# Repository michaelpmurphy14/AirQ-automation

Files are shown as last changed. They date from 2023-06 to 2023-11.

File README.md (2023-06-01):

# AirQ automation
 using ESP32C3 chip to collect and analyze air quality data
# Background
Create a sensor platform that can provide air quality data in a self-contained manner while also having the option to interface with an application.
 
A MiCS524 sensor for CO and a BME680 sensor for VOC, eCO2, and Temp/Humidity will connect to a Seeed Studio XIAO nRF52840 board and will be powered by an internal battery. The board will transmit data to an integrated RGB led and audible alert module and will also push data over BLE and WiFi to an application server. The device will be addressable by a single momentary push-button switch for checking battery status, pairing, etc...
 
The device will be able to be charged through the usb-c port on the nRF52840 board, and battery life will be 5-7 days on a single charge under normal load. The device will connect to any MagSafe device and will be able to provide charge-through capabilities when plugged in, as well as the capability to act as a standalone back-up power-bank to the connected device for a limited period
# Hardware Setup
## Bill of Materials
[Seed XIAO ESP32C3](https://www.seeedstudio.com/Seeed-XIAO-ESP32C3-p-5431.html)

[MICS 5524 Sensor](https://wiki.dfrobot.com/Fermion__MEMS_Gas_Sensor___MiCS-5524_SKU_SEN0440)

[BME680 Sensor](https://www.adafruit.com/product/3660)

[Buzzer]

[RGB Led]

[Li-Po Battery]

[QI Wireless Charging Unit]

## Technical Challenges
### Calibration
Each device will have to manually calibrated to provide an accurate range of gas readings from the MIS5524 Sensor. To compare each sensor and chip configuration, we will use onboard tinyML to calibrate to known values and adjust for drift over time

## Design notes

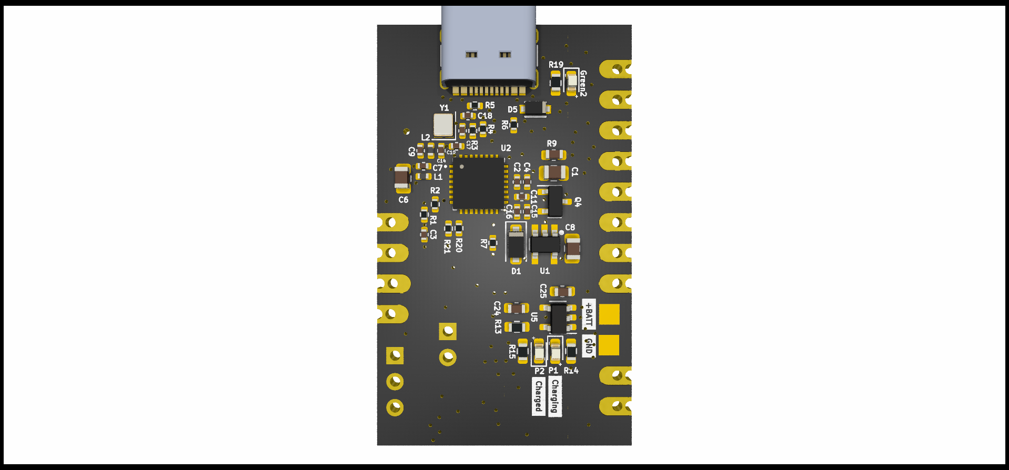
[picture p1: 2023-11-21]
Esp32C3 Project/3D Images/Back 3D.png

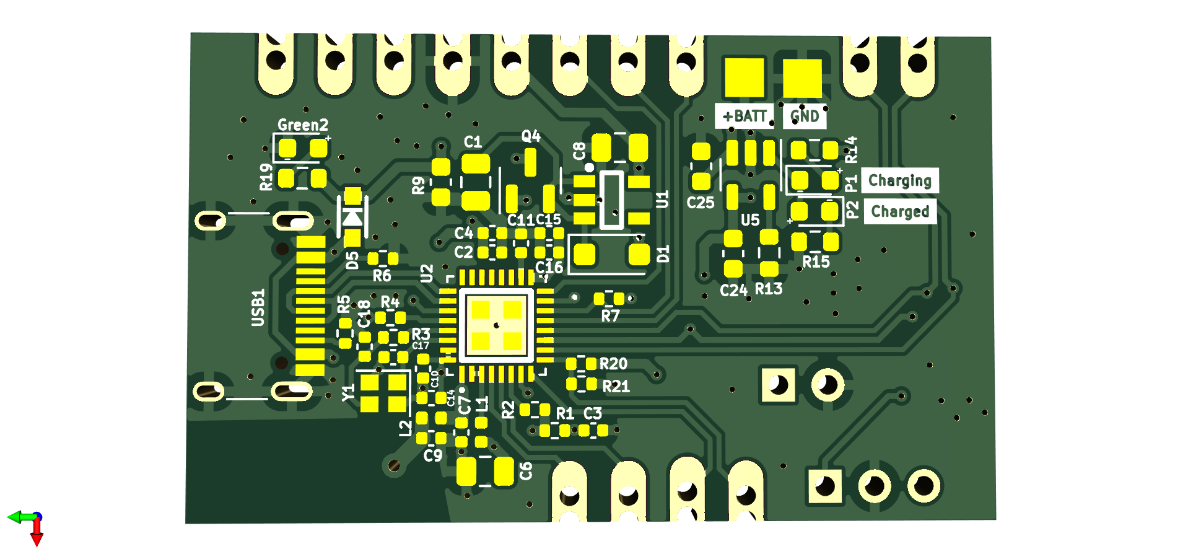
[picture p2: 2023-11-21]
Esp32C3 Project/3D Images/Back 2D.png

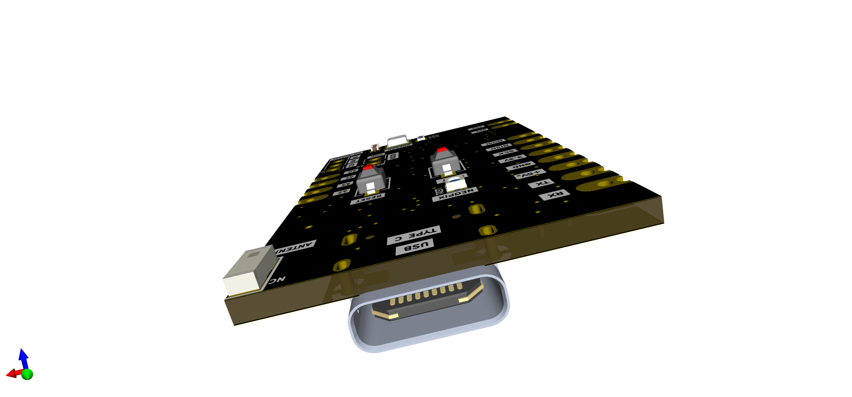
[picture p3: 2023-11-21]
Esp32C3 Project/3D Images/USB.png

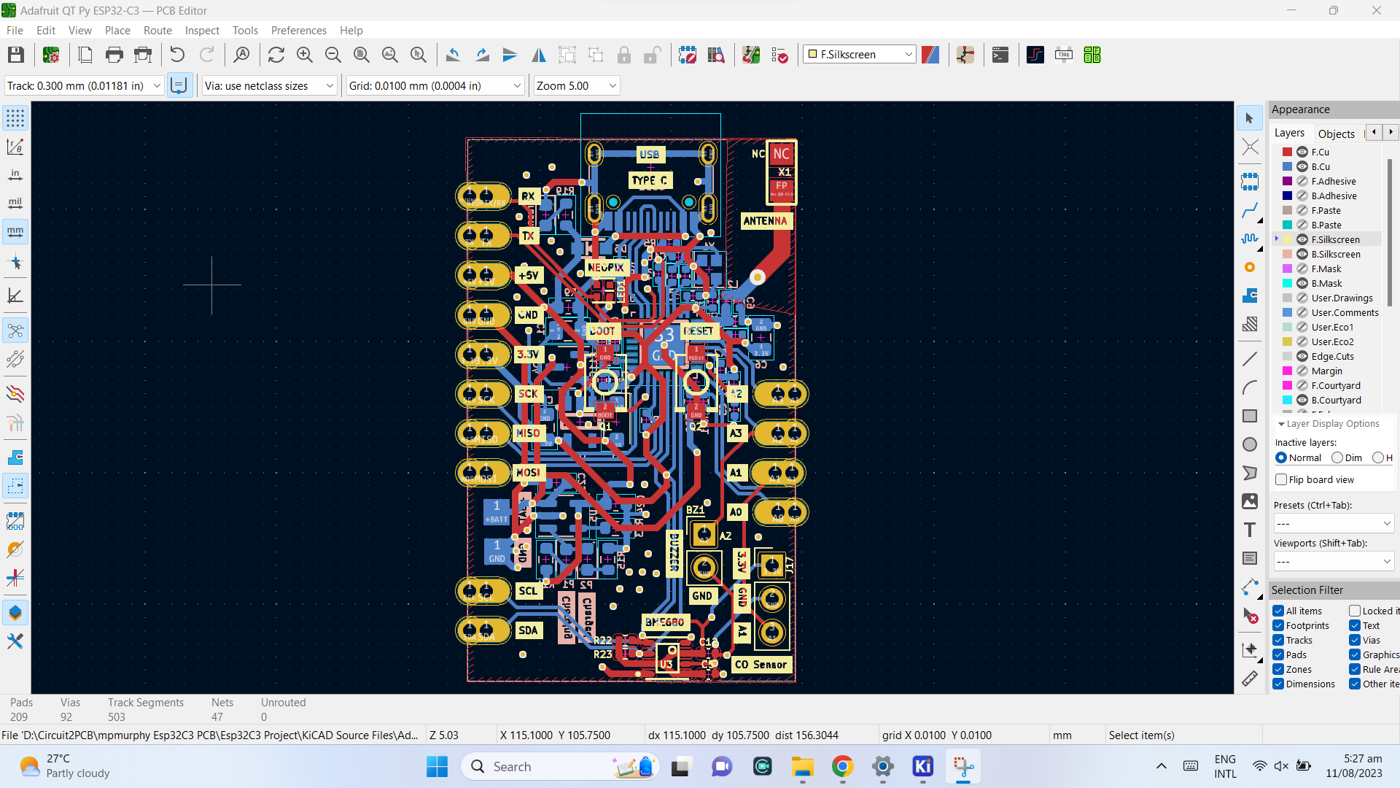
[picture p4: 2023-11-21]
Esp32C3 Project/PCB Layout.png

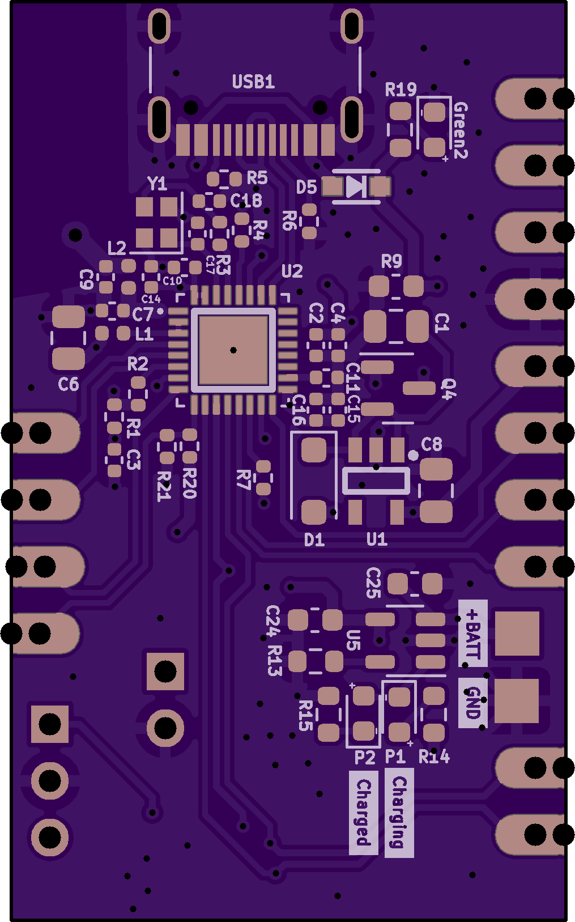
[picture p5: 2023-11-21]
Esp32C3 Project/3D Images/Board Bottom.png

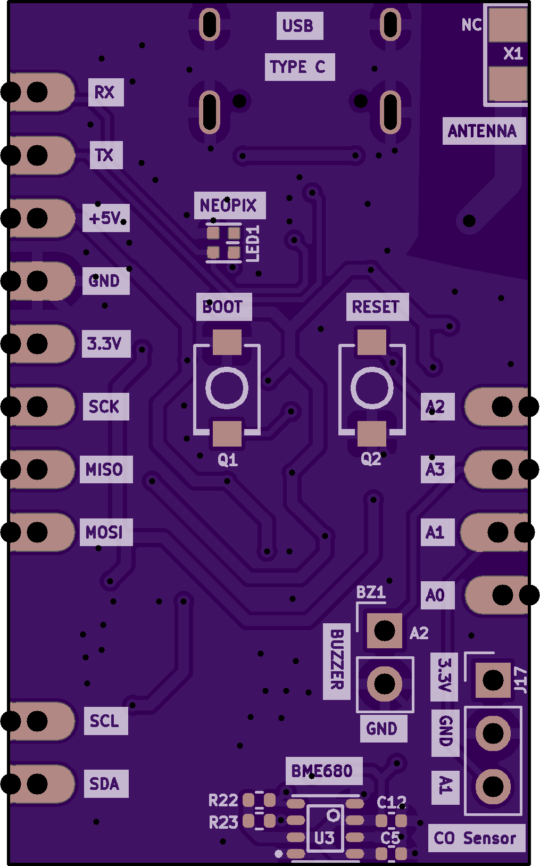
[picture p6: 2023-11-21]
Esp32C3 Project/3D Images/Board Top.png

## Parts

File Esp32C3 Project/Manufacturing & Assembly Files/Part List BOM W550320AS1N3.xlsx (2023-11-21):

Item | Qty | Reference(s) | Value | Footprint | LCSC Part# | Purchase Link
1 | 1 | BZ1 | Buzzer | Connector_PinHeader_2.54mm:PinHeader_1x02_P2.54mm_Vertical | C49661 | https://www.lcsc.com/product-detail/Female-Headers_BOOMELE-Boom-Precision-Elec-C49661_C49661.html
2 | 2 | C1, C8 | 22uF | Ahsan Libs:C_0805_2012Metric | C45783 | https://www.lcsc.com/product-detail/Multilayer-Ceramic-Capacitors-MLCC-SMD-SMT_Samsung-Electro-Mechanics-CL21A226MAQNNNE_C45783.html
3 | 4 | C2, C3, C11, C15 | 1uF | Ahsan Libs:C_0402_1005Metric | C52923 | https://www.lcsc.com/product-detail/Multilayer-Ceramic-Capacitors-MLCC-SMD-SMT_Samsung-Electro-Mechanics-CL05A105KA5NQNC_C52923.html
4 | 5 | C4, C5, C10, C12, C14 | 0.1uF | Ahsan Libs:C_0402_1005Metric | C307331 | https://www.lcsc.com/product-detail/Multilayer-Ceramic-Capacitors-MLCC-SMD-SMT_Samsung-Electro-Mechanics-CL05B104KB54PNC_C307331.html
5 | 1 | C6 | 22uF | Ahsan Libs:C_0805_2012Metric | C45783 | https://www.lcsc.com/product-detail/Multilayer-Ceramic-Capacitors-MLCC-SMD-SMT_Samsung-Electro-Mechanics-CL21A226MAQNNNE_C45783.html
6 | 1 | C7 | 2.7pF | Ahsan Libs:C_0402_1005Metric | C1561 | https://www.lcsc.com/product-detail/Multilayer-Ceramic-Capacitors-MLCC-SMD-SMT_FH-Guangdong-Fenghua-Advanced-Tech-0402CG2R7C500NT_C1561.html
7 | 1 | C9 | 2pF | Ahsan Libs:C_0402_1005Metric | C285089 | https://www.lcsc.com/product-detail/Multilayer-Ceramic-Capacitors-MLCC-SMD-SMT_FH-Guangdong-Fenghua-Advanced-Tech-0402CG2R0B500NT_C285089.html
8 | 1 | C16 | 0.01uF | Ahsan Libs:C_0402_1005Metric | C15195 | https://www.lcsc.com/product-detail/Multilayer-Ceramic-Capacitors-MLCC-SMD-SMT_Samsung-Electro-Mechanics-CL05B103KB5NNNC_C15195.html
9 | 2 | C17, C18 | 16pF | Ahsan Libs:C_0402_1005Metric | C161307 | https://www.lcsc.com/product-detail/Multilayer-Ceramic-Capacitors-MLCC-SMD-SMT_Murata-Electronics-GJM1555C1H160GB01D_C161307.html
10 | 2 | C24, C25 | 10uF | Ahsan Libs:C_0603_1608Metric | C96446 | https://www.lcsc.com/product-detail/Multilayer-Ceramic-Capacitors-MLCC-SMD-SMT_Samsung-Electro-Mechanics-CL10A106MA8NRNC_C96446.html
11 | 1 | D1 | B5817WL | Diode_SMD:D_SOD-123F | C122853 | https://www.lcsc.com/product-detail/Schottky-Barrier-Diodes-SBD_Shikues-B5817WL_C122853.html
12 | 1 | D5 | NSR0320 | Esp32-C3:SOD-323_MINI | C48192 | https://www.lcsc.com/product-detail/Schottky-Barrier-Diodes-SBD_onsemi-NSR0320MW2T1G_C48192.html
13 | 1 | Green2 | Power | Ahsan Libs:LED_0603_1608Metric | C72041 | https://www.lcsc.com/product-detail/Light-Emitting-Diodes-LED_Everlight-Elec-19-217-BHC-ZL1M2RY-3T_C72041.html
14 | 1 | J17 | CO Sensor | Connector_PinHeader_2.54mm:PinHeader_1x03_P2.54mm_Vertical | C541850 | https://www.lcsc.com/product-detail/Female-Headers_XFCN-PM254V-11-03-H85_C541850.html
15 | 1 | L1 | 2nH | Inductor_SMD:L_0402_1005Metric | C98758 | https://www.lcsc.com/product-detail/Inductors-SMD_TDK-MLG1005S2N0CT000_C98758.html
16 | 1 | L2 | 2.2nH | Inductor_SMD:L_0402_1005Metric | C91240 | https://www.lcsc.com/product-detail/Inductors-SMD_Murata-Electronics-LQW15AN2N2C10D_C91240.html
17 | 1 | LED1 | WS2812B_SK6805_1515 | Esp32-C3:SK6805_1515 | C2890035 | https://www.lcsc.com/product-detail/Light-Emitting-Diodes-LED_OPSCO-Optoelectronics-SK6805-EC15_C2890035.html
18 | 1 | P1 | Charging | Ahsan Libs:LED_0603_1608Metric | C125094 | https://www.lcsc.com/product-detail/Light-Emitting-Diodes-LED_Lite-On-LTST-C190KGKT_C125094.html
19 | 1 | P2 | Charged | Ahsan Libs:LED_0603_1608Metric | C125099 | https://www.lcsc.com/product-detail/Light-Emitting-Diodes-LED_Lite-On-LTST-C191KRKT_C125099.html
20 | 1 | Q1 | BOOT | Ahsan Libs:SW-SMD-TS-1088-AR02016 | C720477 | https://www.lcsc.com/product-detail/Tactile-Switches_XUNPU-TS-1088-AR02016_C720477.html
21 | 1 | Q2 | RESET | Ahsan Libs:SW-SMD-TS-1088-AR02016 | C720477 | https://www.lcsc.com/product-detail/Tactile-Switches_XUNPU-TS-1088-AR02016_C720477.html
22 | 1 | Q4 | AO3401A | Package_TO_SOT_SMD:SOT-23 | C15127 | https://www.lcsc.com/product-detail/MOSFETs_Alpha-Omega-Semicon-AO3401A_C15127.html
23 | 2 | R1, R2 | 10K | Ahsan Libs:R_0402_1005Metric | C25744 | https://www.lcsc.com/product-detail/Chip-Resistor-Surface-Mount_UNI-ROYAL-Uniroyal-Elec-0402WGF1002TCE_C25744.html
24 | 1 | R3 | 0 | Ahsan Libs:R_0402_1005Metric | C17168 | https://www.lcsc.com/product-detail/Chip-Resistor-Surface-Mount_UNI-ROYAL-Uniroyal-Elec-0402WGF0000TCE_C17168.html
25 | 1 | R4 | 1k | Ahsan Libs:R_0402_1005Metric | C11702 | https://www.lcsc.com/product-detail/Chip-Resistor-Surface-Mount_UNI-ROYAL-Uniroyal-Elec-0402WGF1001TCE_C11702.html
26 | 2 | R5, R6 | 5.1k | Ahsan Libs:R_0402_1005Metric | C25905 | https://www.lcsc.com/product-detail/Chip-Resistor-Surface-Mount_UNI-ROYAL-Uniroyal-Elec-0402WGF5101TCE_C25905.html
27 | 1 | R7 | 10K | Ahsan Libs:R_0402_1005Metric | C25744 | https://www.lcsc.com/product-detail/Chip-Resistor-Surface-Mount_UNI-ROYAL-Uniroyal-Elec-0402WGF1002TCE_C25744.html
28 | 1 | R9 | 806K | Ahsan Libs:C_0603_1608Metric | C23250 | https://www.lcsc.com/product-detail/Chip-Resistor-Surface-Mount_UNI-ROYAL-Uniroyal-Elec-0603WAF8063T5E_C23250.html
29 | 1 | R13 | 2K | Ahsan Libs:R_0603_1608Metric | C22975 | https://www.lcsc.com/product-detail/Chip-Resistor-Surface-Mount_UNI-ROYAL-Uniroyal-Elec-0603WAF2001T5E_C22975.html
30 | 3 | R14, R15, R19 | 470 | Ahsan Libs:R_0603_1608Metric | C23179 | https://www.lcsc.com/product-detail/Chip-Resistor-Surface-Mount_UNI-ROYAL-Uniroyal-Elec-0603WAF4700T5E_C23179.html
31 | 2 | R20, R21 | 220k | Ahsan Libs:R_0402_1005Metric | C25767 | https://www.lcsc.com/product-detail/Chip-Resistor-Surface-Mount_UNI-ROYAL-Uniroyal-Elec-0402WGF2203TCE_C25767.html
32 | 2 | R22, R23 | 4.7k | Ahsan Libs:R_0402_1005Metric | C25900 | https://www.lcsc.com/product-detail/Chip-Resistor-Surface-Mount_UNI-ROYAL-Uniroyal-Elec-0402WGF4701TCE_C25900.html
33 | 1 | U1 | AP2112K-3.3 | Ahsan Libs:SOT-25-5_L3.0-W1.8-P0.95-LS3.0-BR | C51118 | https://www.lcsc.com/product-detail/Linear-Voltage-Regulators-LDO_Diodes-Incorporated-AP2112K-3-3TRG1_C51118.html
34 | 1 | U2 | ESP32-C3FH4 | Esp32-C3:QFN32_5MM | C2858491 | https://www.lcsc.com/product-detail/Microcontroller-Units-MCUs-MPUs-SOCs_Espressif-Systems-ESP32-C3FH4_C2858491.html
35 | 1 | U3 | BME680 | Ahsan Libs:BME680-LGA-8_L3.0-W3.0-P0.80-TR | C125972 | https://www.lcsc.com/product-detail/Temperature-and-Humidity-Sensor_Bosch-Sensortec-BME680_C125972.html
36 | 1 | U5 | MCP73831-2-OT | Package_TO_SOT_SMD:SOT-23-5 | C424093 | https://www.lcsc.com/product-detail/Battery-Management-ICs_Microchip-Tech-MCP73831T-2ACI-OT_C424093.html
37 | 1 | USB1 | USB_C_Receptacle_USB2.0 | Ahsan Libs:USB_C_Receptacle_HRO_TYPE-C-31-M-12 | C165948 | https://www.lcsc.com/product-detail/USB-Connectors_Korean-Hroparts-Elec-TYPE-C-31-M-12_C165948.html
38 | 1 | X1 | 2.4GHz | Esp32-C3:ANT_2450AT18B100 | C89334 | https://www.lcsc.com/product-detail/Antennas_Johanson-Dielectrics-2450AT18A100E_C89334.html
39 | 1 | Y1 | 40MHz | Crystal:Crystal_SMD_2016-4Pin_2.0x1.6mm | C501798 | https://www.lcsc.com/product-detail/Crystals_TST-TZ1269D_C501798.html

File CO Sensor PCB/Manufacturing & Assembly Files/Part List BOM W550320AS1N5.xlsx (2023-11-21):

Item | Qty | Reference(s) | Value | Footprint | LCSC Part# | Purchase Link
1 | 1 | J17 | CO Sensor Conn | Connector_PinHeader_2.54mm:PinHeader_1x03_P2.54mm_Vertical | C2937625 | https://www.lcsc.com/product-detail/Pin-Headers_XFCN-PZ254V-11-03P_C2937625.html
2 | 2 | R1, R2 | 10K | Ahsan Libs:R_0805_2012Metric | C17414 | https://www.lcsc.com/product-detail/Chip-Resistor-Surface-Mount_UNI-ROYAL-Uniroyal-Elec-0805W8F1002T5E_C17414.html
3 | 1 | R3 | 100K | Ahsan Libs:R_0805_2012Metric | C149504 | https://www.lcsc.com/product-detail/Chip-Resistor-Surface-Mount_UNI-ROYAL-Uniroyal-Elec-0805W8F1003T5E_C149504.html
4 | 1 | U4 | 110-102 | Ahsan Libs:CO Sensor | Carbon Monoxide (CO) Sensor Current | https://www.digikey.com/en/products/detail/spec-sensors-llc/110-102/6136363

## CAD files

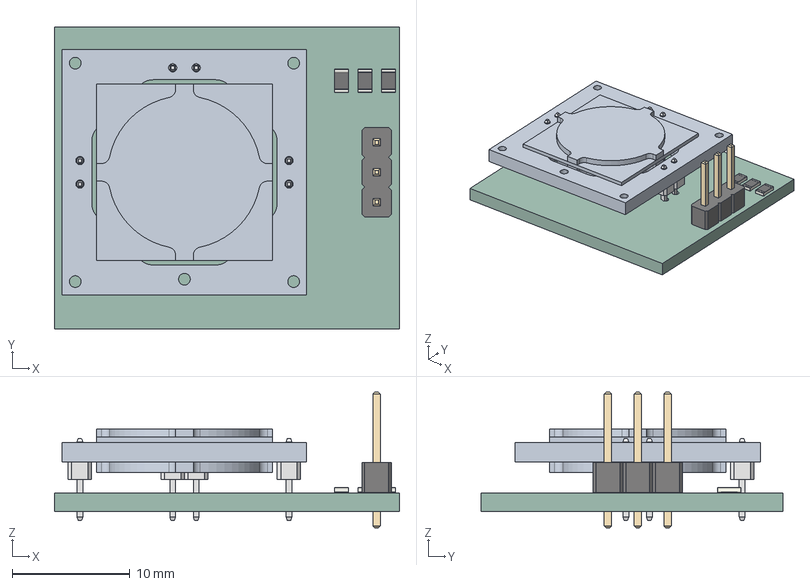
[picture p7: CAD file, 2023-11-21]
CO Sensor PCB/3D Step File/PCB CO Sesnor 3D.step
29.3 x 25.7 x 11.5 mm
_autosave-CO Sesnor Breakout PCB

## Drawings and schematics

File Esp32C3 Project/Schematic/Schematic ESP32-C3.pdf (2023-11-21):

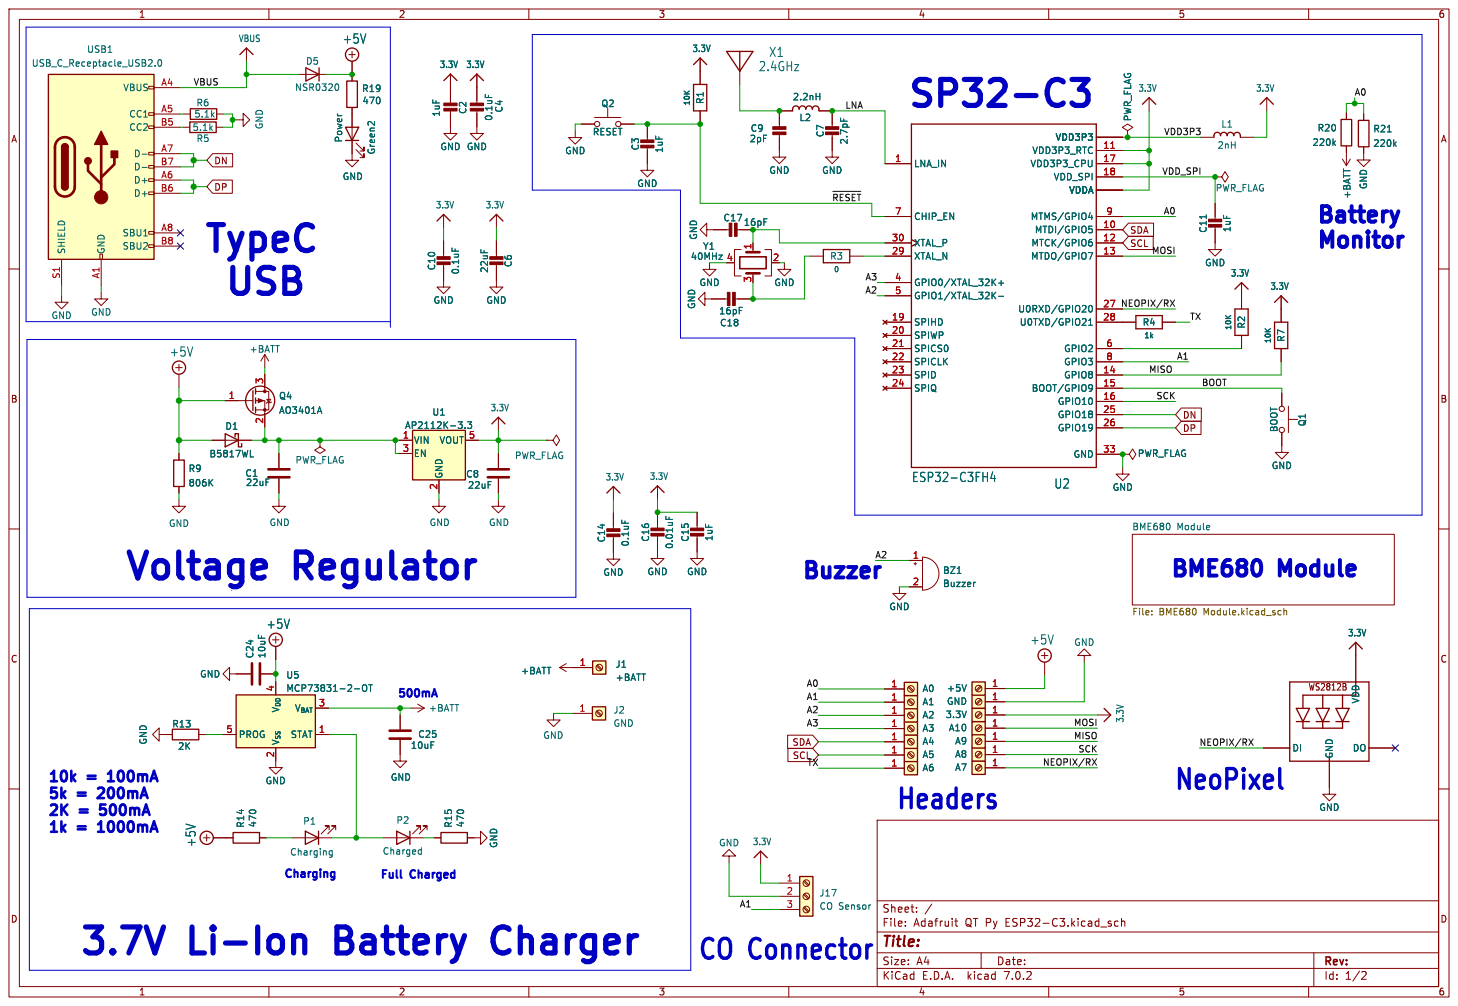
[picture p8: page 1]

2 EN 3 VOUT 5 U1 AP2112K-3.3 GND GND GND GND Q2 RESET X1

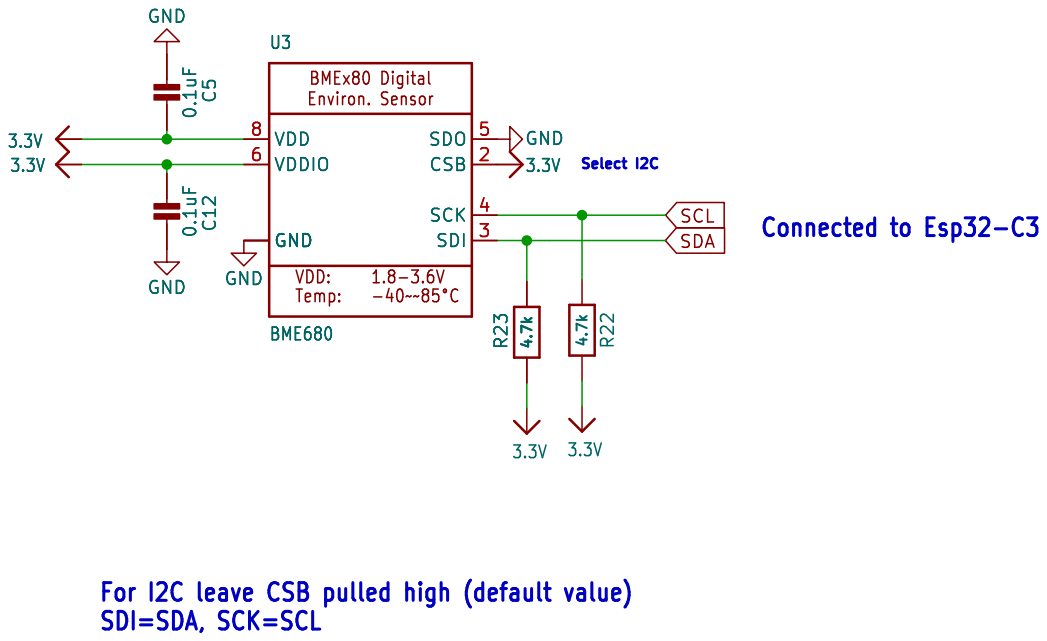
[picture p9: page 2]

SDI=SDA, SCK=SCL

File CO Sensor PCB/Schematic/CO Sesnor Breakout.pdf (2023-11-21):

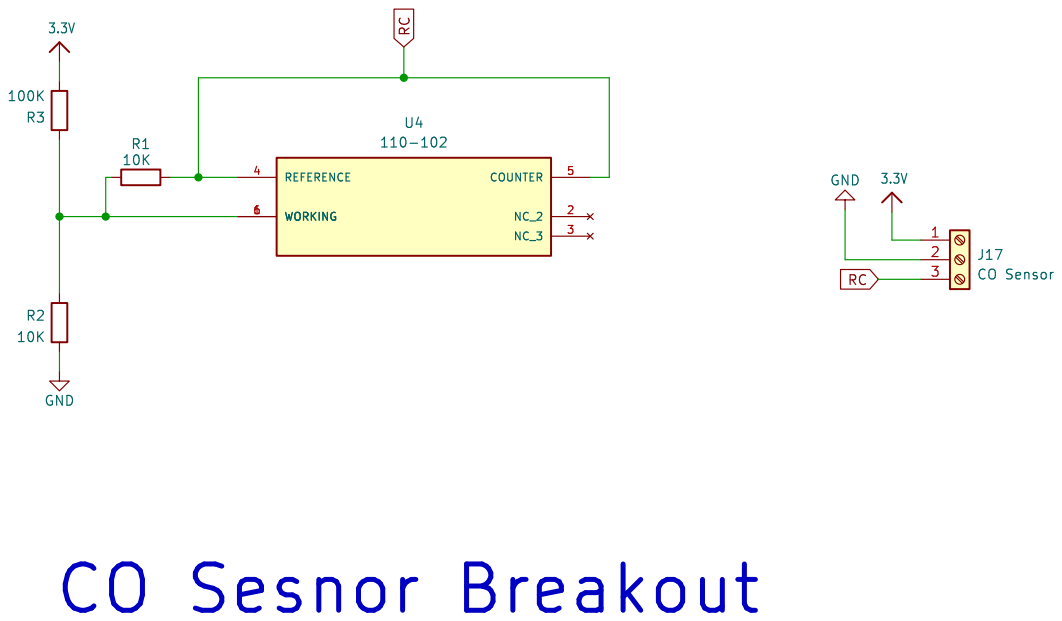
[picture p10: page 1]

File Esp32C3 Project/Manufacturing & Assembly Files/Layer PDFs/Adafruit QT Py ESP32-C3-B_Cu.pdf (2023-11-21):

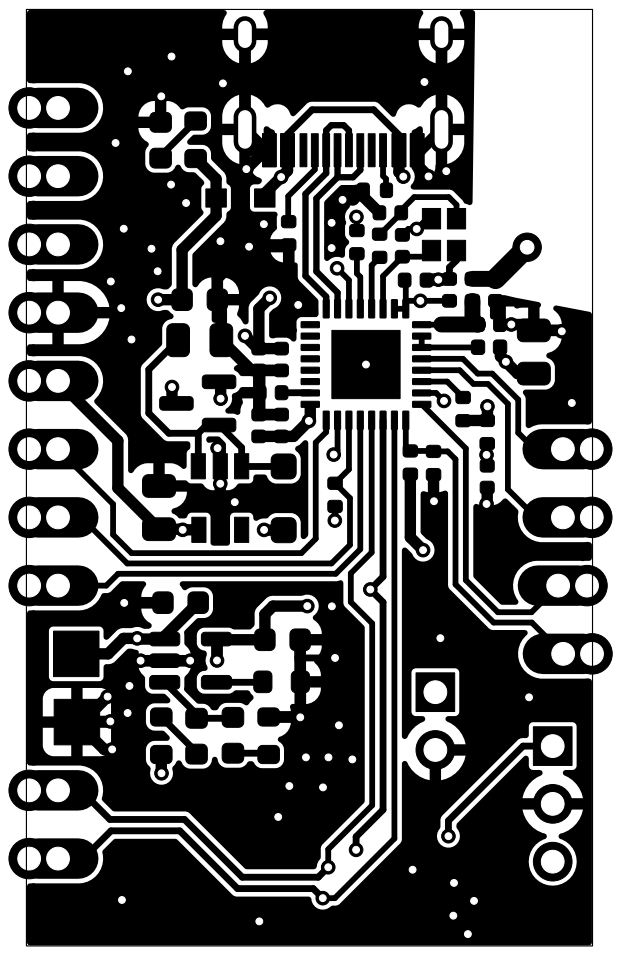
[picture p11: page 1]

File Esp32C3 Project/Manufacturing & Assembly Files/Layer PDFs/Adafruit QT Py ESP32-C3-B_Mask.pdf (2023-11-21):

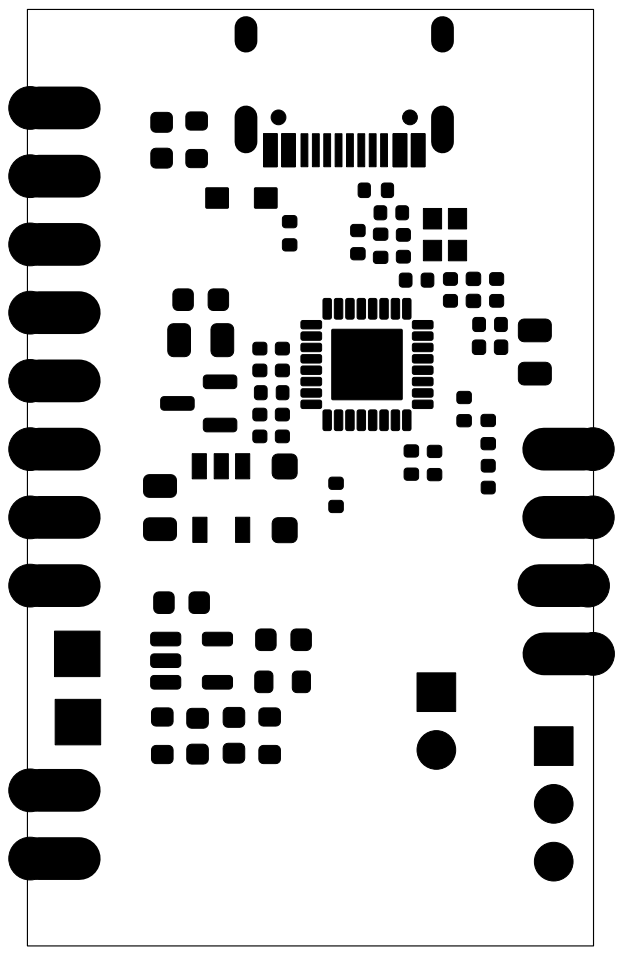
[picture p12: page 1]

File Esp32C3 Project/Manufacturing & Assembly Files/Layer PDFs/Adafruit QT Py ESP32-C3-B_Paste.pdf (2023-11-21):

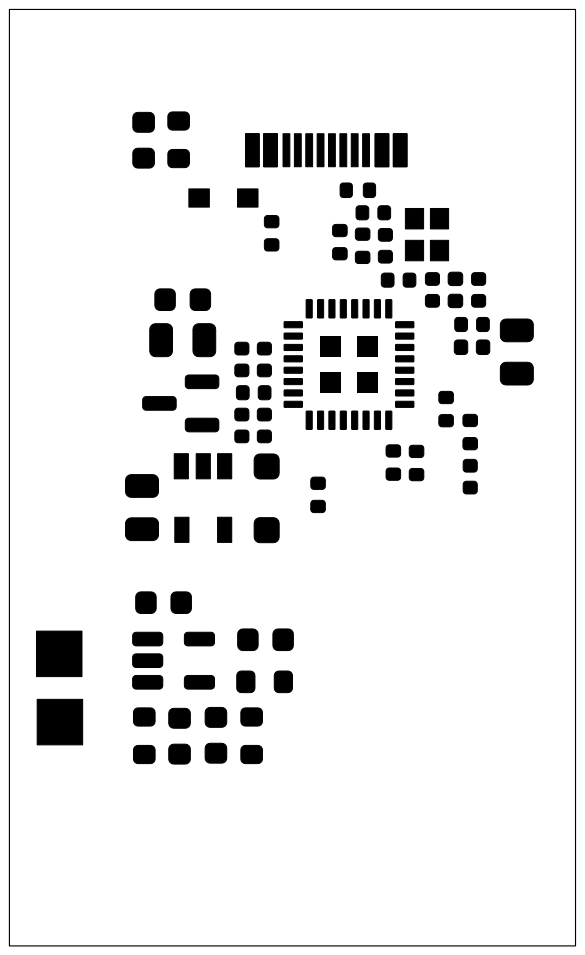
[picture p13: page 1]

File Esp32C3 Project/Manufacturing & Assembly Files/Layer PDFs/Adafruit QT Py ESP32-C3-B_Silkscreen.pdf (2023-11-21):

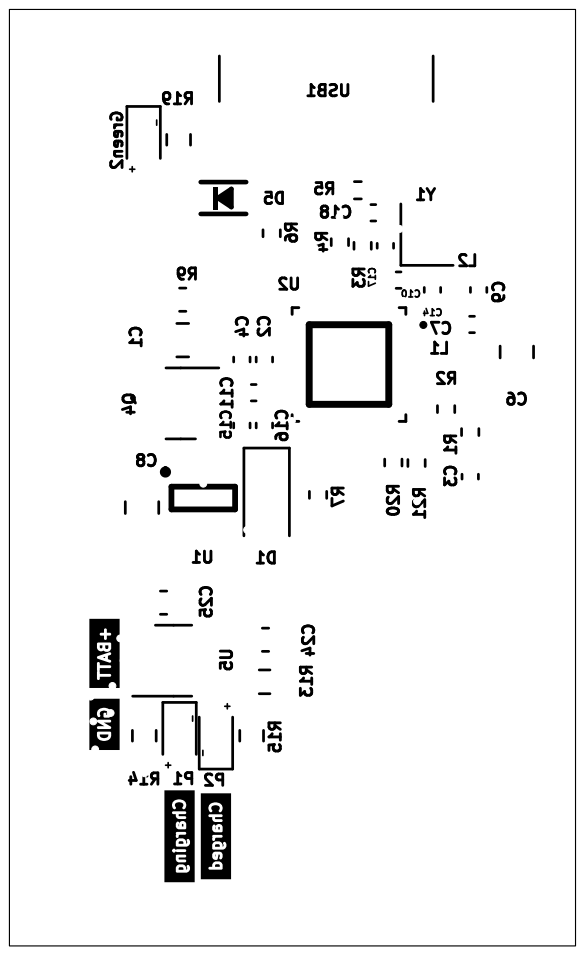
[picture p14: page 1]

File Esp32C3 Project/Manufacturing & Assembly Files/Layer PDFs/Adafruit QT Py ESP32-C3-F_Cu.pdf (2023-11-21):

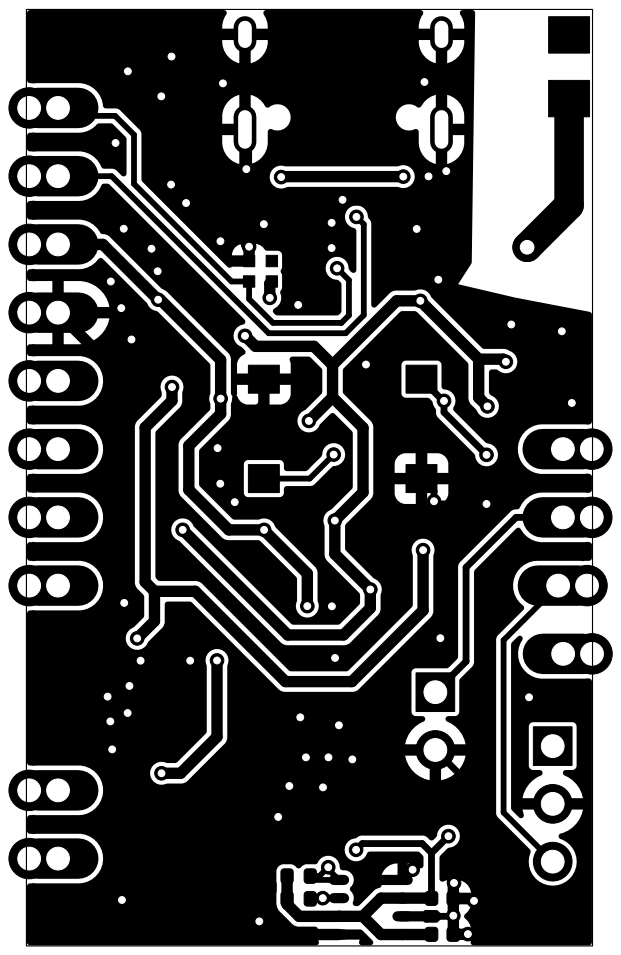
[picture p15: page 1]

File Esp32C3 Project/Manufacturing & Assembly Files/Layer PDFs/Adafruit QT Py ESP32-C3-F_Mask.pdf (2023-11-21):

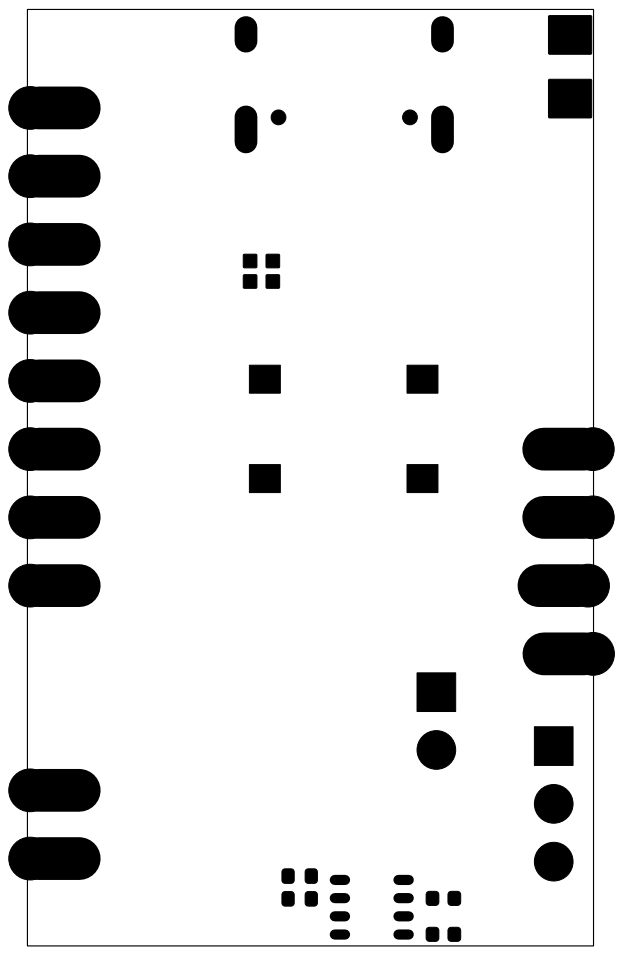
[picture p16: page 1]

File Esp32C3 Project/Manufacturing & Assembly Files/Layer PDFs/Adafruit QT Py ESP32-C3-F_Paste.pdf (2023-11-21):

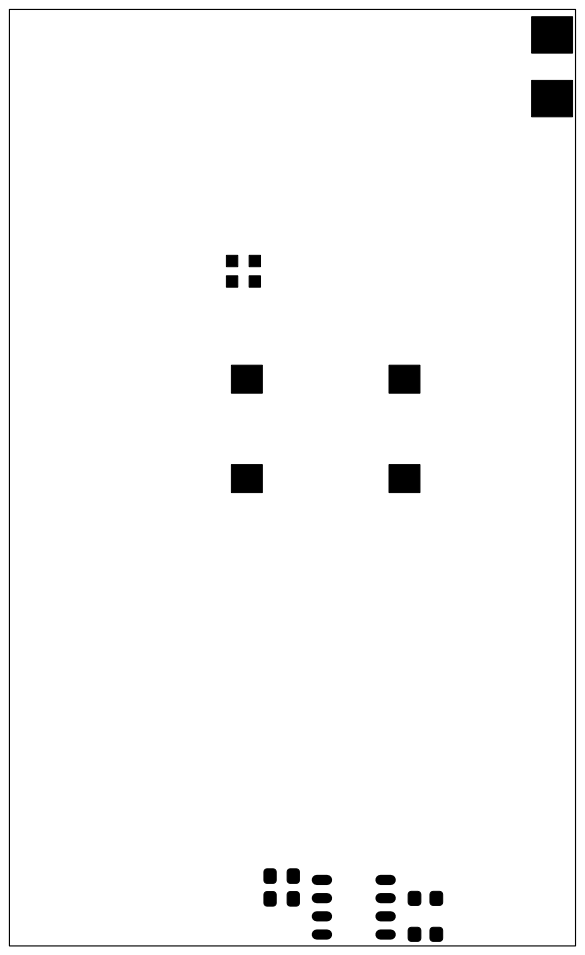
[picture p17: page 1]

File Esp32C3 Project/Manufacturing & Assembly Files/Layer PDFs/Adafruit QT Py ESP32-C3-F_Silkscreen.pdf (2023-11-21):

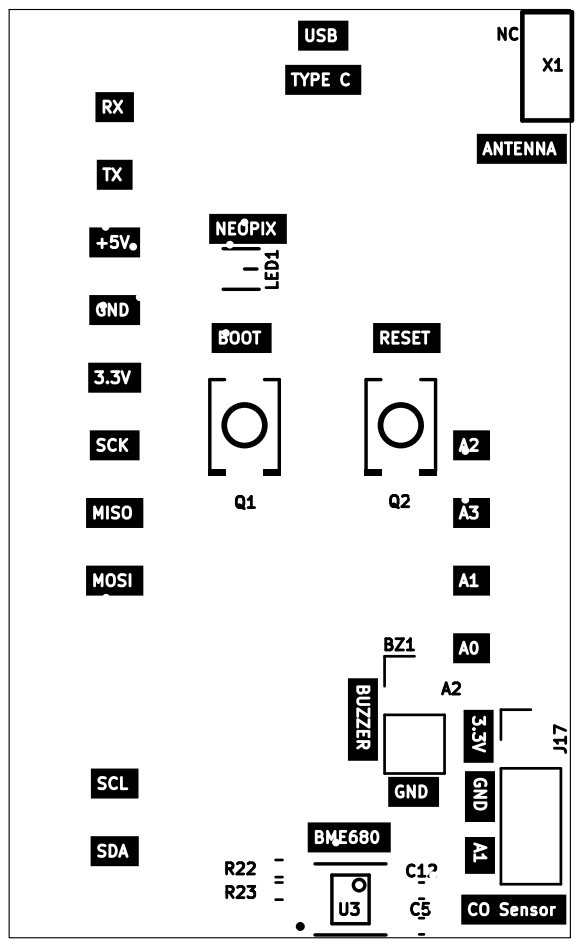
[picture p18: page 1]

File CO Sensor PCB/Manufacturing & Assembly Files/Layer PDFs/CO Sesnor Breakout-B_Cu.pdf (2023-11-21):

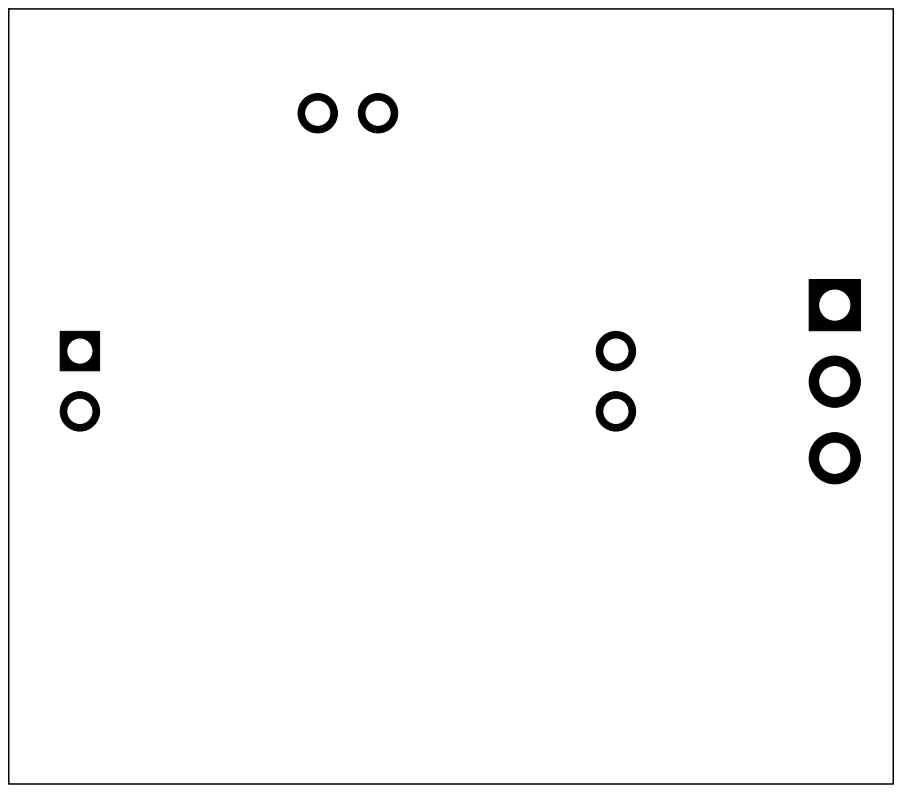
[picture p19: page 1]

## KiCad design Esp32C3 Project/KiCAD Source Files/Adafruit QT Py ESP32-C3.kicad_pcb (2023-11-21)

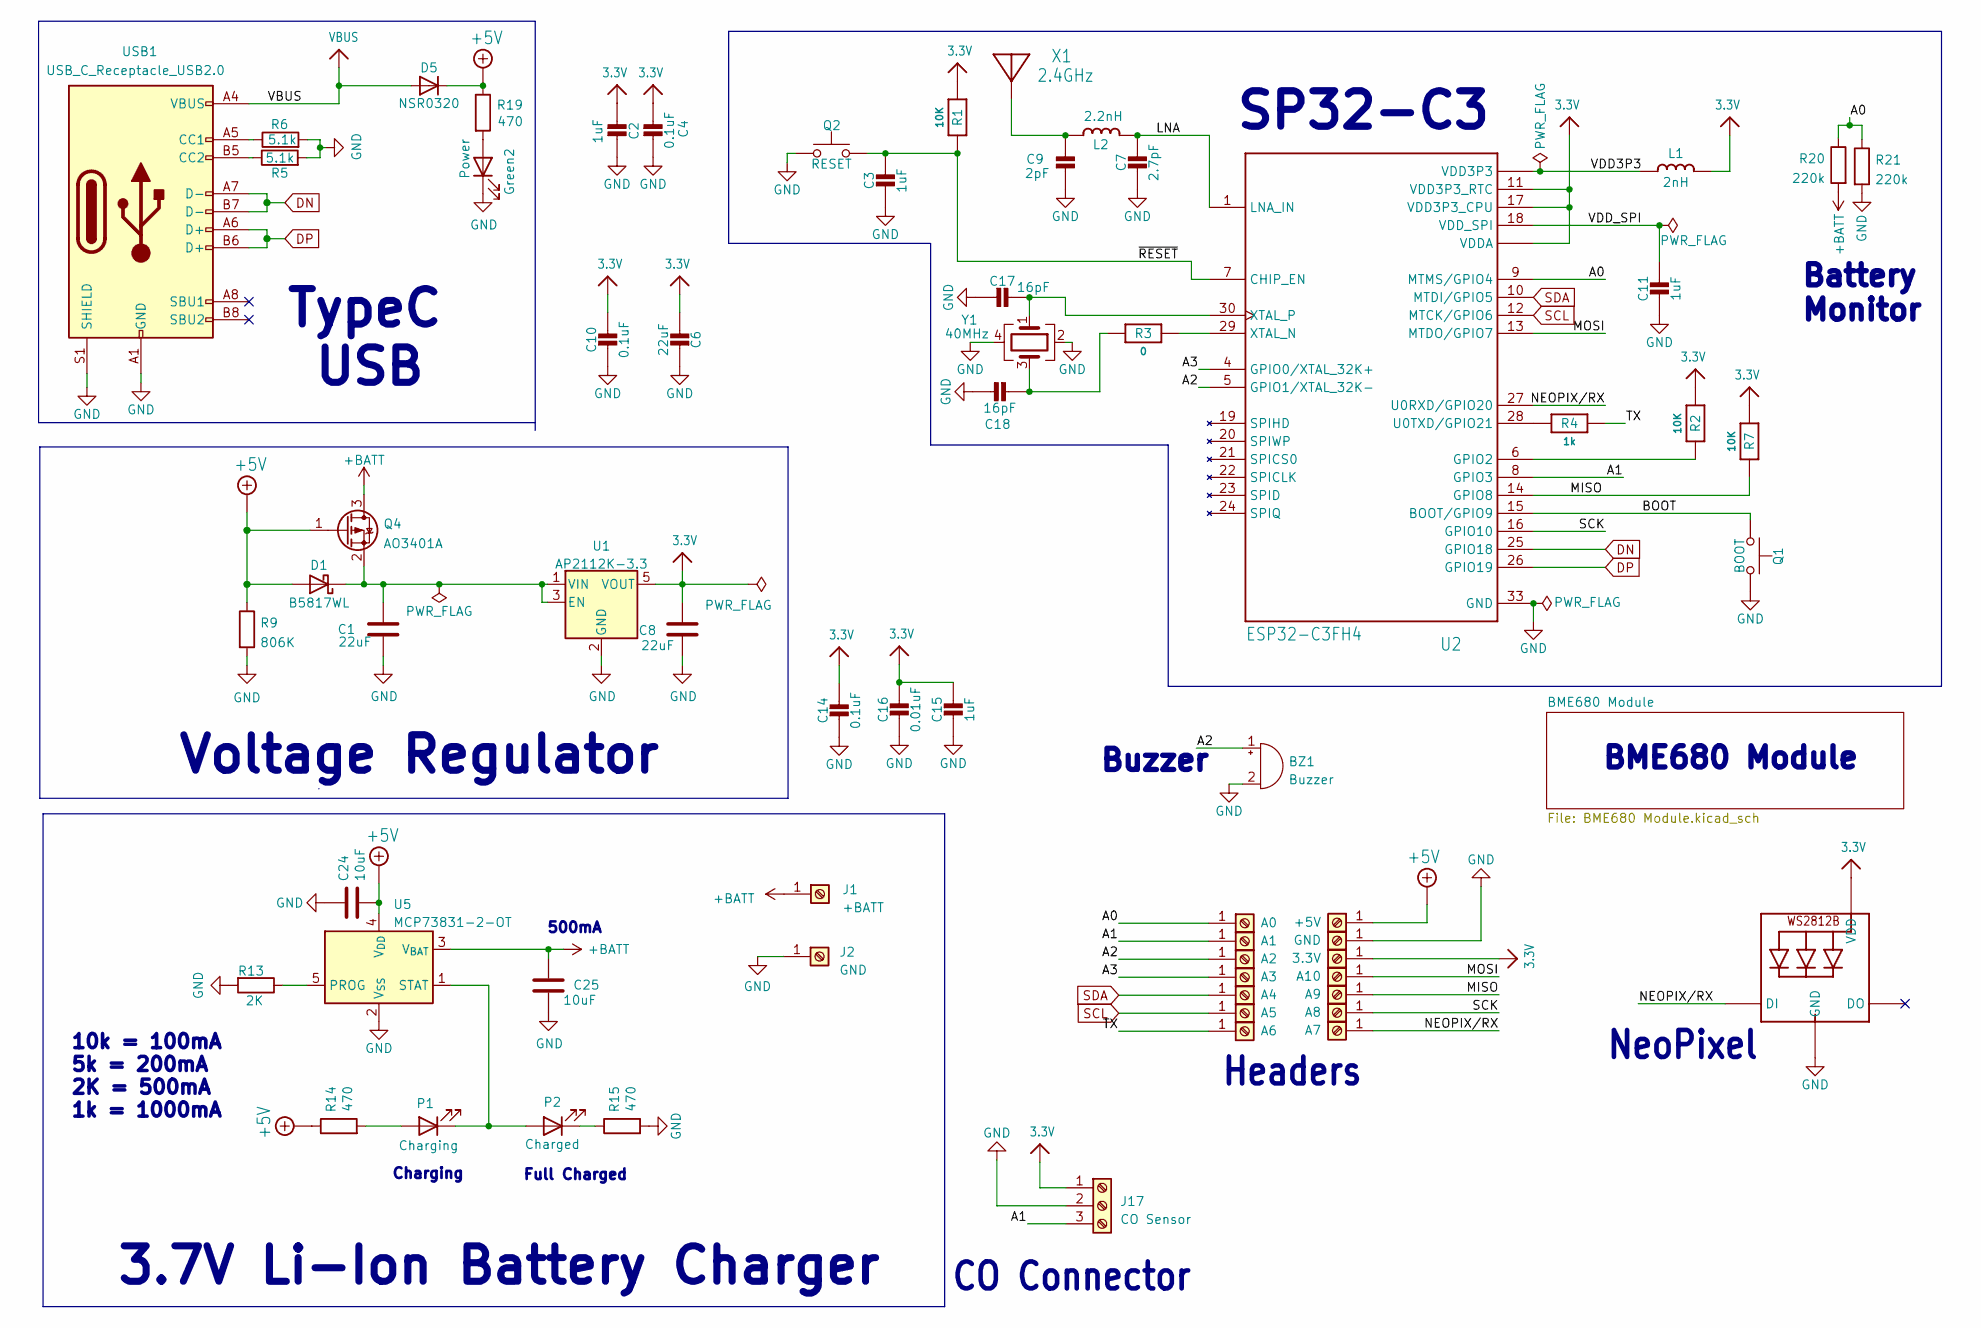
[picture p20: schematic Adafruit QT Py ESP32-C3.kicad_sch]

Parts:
BZ1: Buzzer; PinHeader_1x02_P2.54mm_Vertical
C1, C6, C8: 22uF; C_0805_2012Metric
C2, C3, C11, C15: 1uF; C_0402_1005Metric
C4, C10, C14: 0.1uF; C_0402_1005Metric
C7: 2.7pF; C_0402_1005Metric
C9: 2pF; C_0402_1005Metric
C16: 0.01uF; C_0402_1005Metric
C17, C18: 16pF; C_0402_1005Metric
C24: 10uF; C_0603_1608Metric
C25: 10uF; C_0603_1608Metric; LCSC C19702
D1: B5817WL; D_SOD-123F; LCSC C122853
D5: NSR0320; SOD-323_MINI; LCSC C48192
Green2: Power; LED_0603_1608Metric; LCSC C72041
J1: +BATT; 2x2_SMD_Conn
J2: GND; 2x2_SMD_Conn
J3: A0; 1X01_CASTEL
J4: A1; 1X01_CASTEL
J5: A2; 1X01_CASTEL
J6: A3; 1X01_CASTEL
J7: A4; 1X01_CASTEL
J8: A5; 1X01_CASTEL
J9: A6; 1X01_CASTEL
J10: +5V; 1X01_CASTEL
J11: GND; 1X01_CASTEL
J12: 3.3V; 1X01_CASTEL
J13: A10; 1X01_CASTEL
J14: A9; 1X01_CASTEL
J15: A8; 1X01_CASTEL
J16: A7; 1X01_CASTEL
J17: CO Sensor; PinHeader_1x03_P2.54mm_Vertical
L1: 2nH; L_0402_1005Metric
L2: 2.2nH; L_0402_1005Metric
LED1: WS2812B_SK6805_1515; SK6805_1515; LCSC C2890035
P1: Charging; LED_0603_1608Metric; LCSC C72041
P2: Charged; LED_0603_1608Metric; LCSC C72041
Q1: BOOT; SW-SMD-TS-1088-AR02016; LCSC C720477
Q2: RESET; SW-SMD-TS-1088-AR02016; LCSC C720477
Q4: AO3401A; SOT-23; LCSC C15127
R1, R2, R7: 10K; R_0402_1005Metric
R3: 0; R_0402_1005Metric
R4: 1k; R_0402_1005Metric
R5, R6: 5.1k; R_0402_1005Metric
R9: 806K; C_0603_1608Metric; LCSC C23250
R13: 2K; R_0603_1608Metric
R14, R15, R19: 470; R_0603_1608Metric
R20, R21: 220k; R_0402_1005Metric
U1: AP2112K-3.3; SOT-25-5_L3.0-W1.8-P0.95-LS3.0-BR
U2: ESP32-C3FH4; QFN32_5MM
U5: MCP73831-2-OT; SOT-23-5
USB1: USB_C_Receptacle_USB2.0; USB_C_Receptacle_HRO_TYPE-C-31-M-12
X1: 2.4GHz; ANT_2450AT18B100; LCSC C89334
Y1: 40MHz; Crystal_SMD_2016-4Pin_2.0x1.6mm; LCSC C501798

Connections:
+5V: C24.1, D1.2 (A), D5.C, J10.1, Q4.1 (G), R9.1, R14.1, R19.1, U5.4 (V_{DD})
+BATT: C25.1, J1.1, Q4.3 (D), R20.2, U5.3 (V_{BAT})
/A0: J3.1, R20.1, R21.1, U2.9 (MTMS/GPIO4)
/A1: J4.1, J17.3, U2.8 (GPIO3)
/A2: BZ1.1 (-), J5.1, U2.5 (GPIO1/XTAL_32K-)
/A3: J6.1, U2.4 (GPIO0/XTAL_32K+)
/BOOT: Q1.2, U2.15 (BOOT/GPIO9)
/LNA: C7.1, L2.1, U2.1 (LNA_IN)
/MISO: J14.1, R7.2, U2.14 (GPIO8)
/MOSI: J13.1, U2.13 (MTDO/GPIO7)
/NEOPIX/RX: J16.1, LED1.1 (DI), U2.27 (U0RXD/GPIO20)
/SCK: J15.1, U2.16 (GPIO10)
/TX: J9.1, R4.2
/VDD3P3: L1.2, U2.2 (VDD3P3), U2.3 (VDD3P3)
/VDD_SPI: C11.1, U2.18 (VDD_SPI)
/~RESET: C3.1, Q2.1, R1.2, U2.7 (CHIP_EN)
DN: U2.25 (GPIO18), USB1.A7 (D-), USB1.B7 (D-)
DP: U2.26 (GPIO19), USB1.A6 (D+), USB1.B6 (D+)
unnamed: C18.1, R3.1, Y1.3
unnamed: C1.1, D1.1 (K), Q4.2 (S), U1.1 (VIN), U1.3 (EN)
unnamed: Green2.2 (A), R19.2
unnamed: P1.2 (A), R14.2
unnamed: P1.1 (K), P2.2 (A), U5.1 (STAT)
unnamed: P2.1 (K), R15.1
unnamed: R2.2, U2.6 (GPIO2)
unnamed: R4.1, U2.28 (U0TXD/GPIO21)
unnamed: R3.2, U2.29 (XTAL_N)
unnamed: C17.1, U2.30 (XTAL_P), Y1.1
unnamed: R13.1, U5.5 (PROG)
unnamed: R6.1, USB1.A5 (CC1)
unnamed: R5.1, USB1.B5 (CC2)
unnamed: C9.1, L2.2, X1.FP
SCL: J8.1, U2.12 (MTCK/GPIO6); also elsewhere on the board
SDA: J7.1, U2.10 (MTDI/GPIO5); also elsewhere on the board
VBUS: D5.A, USB1.A4 (VBUS), USB1.A9 (VBUS), USB1.B4 (VBUS), USB1.B9 (VBUS)

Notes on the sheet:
Headers
NeoPixel
CO Connector
Battery Monitor
Buzzer
10k = 100mA 5k = 200mA 2K = 500mA 1k = 1000mA
3.7V Li-Ion Battery Charger
TypeC
BME680 Module
500mA
Voltage Regulator
Charging
Full Charged
USB
SP32-C3

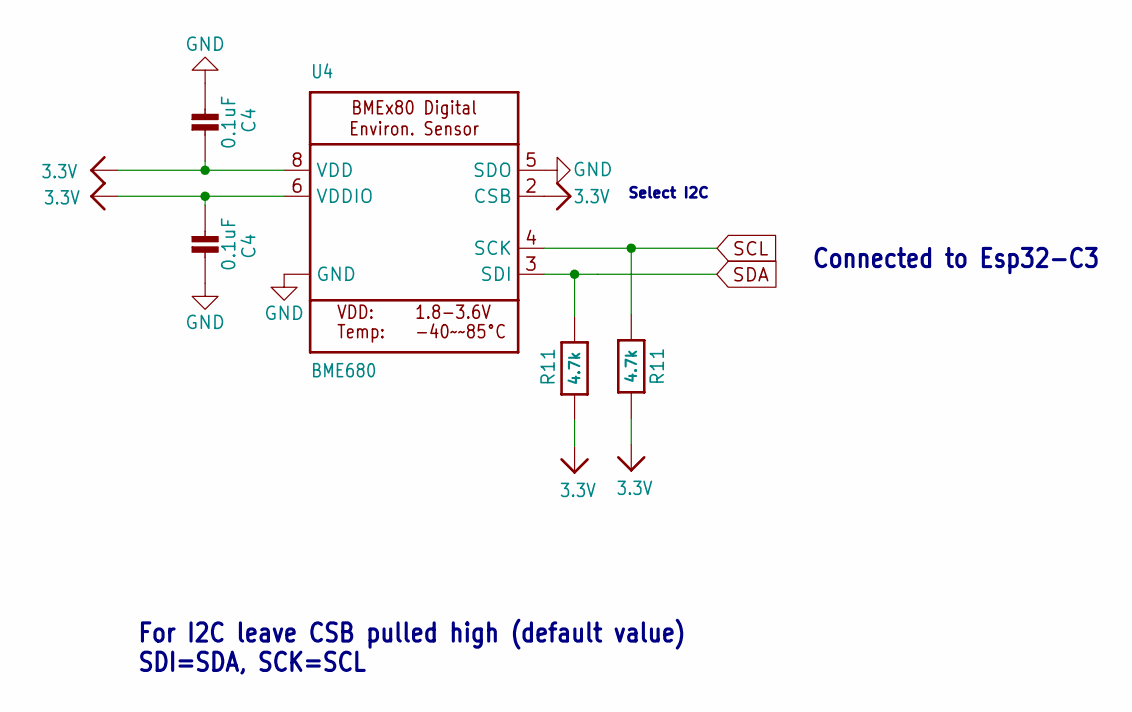
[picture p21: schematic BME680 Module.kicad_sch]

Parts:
C4: 0.1uF; C_0402_1005Metric
R11: 4.7k; R_0402_1005Metric
U4: BME680; BME680-LGA-8_L3.0-W3.0-P0.80-TR; LCSC C125972

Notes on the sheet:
Select I2C
Connected to Esp32-C3
For I2C leave CSB pulled high (default value) SDI=SDA, SCK=SCL

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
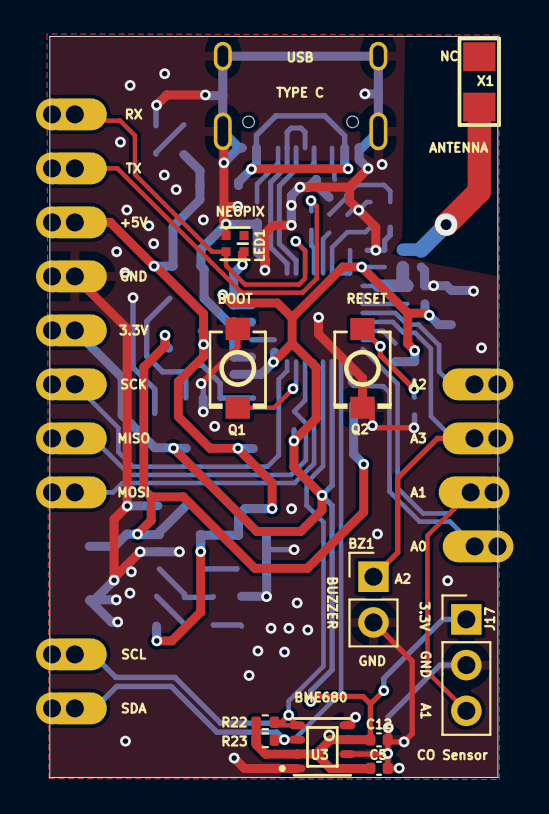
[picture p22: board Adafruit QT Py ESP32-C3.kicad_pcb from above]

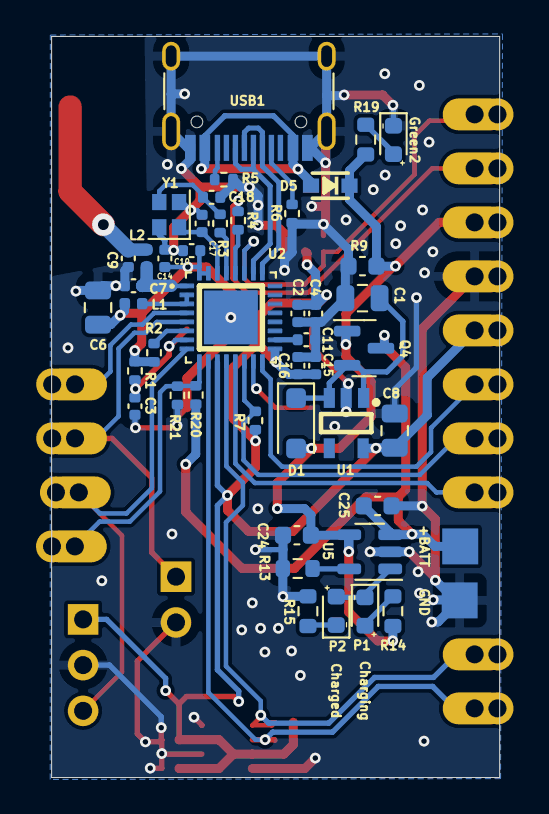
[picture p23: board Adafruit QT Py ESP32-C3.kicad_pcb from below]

Board: 2 copper layers, 24.9 x 41.2 mm, 71 parts (46 on the bottom side), 37 nets.

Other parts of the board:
C5, C12: 0.1uF; C_0402_1005Metric
R22, R23: 4.7k; R_0402_1005Metric
U3: BME680; BME680-LGA-8_L3.0-W3.0-P0.80-TR

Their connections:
SCL: R22.1, U3.4 (SCK); also elsewhere on the board
SDA: R23.1, U3.3 (SDI); also elsewhere on the board

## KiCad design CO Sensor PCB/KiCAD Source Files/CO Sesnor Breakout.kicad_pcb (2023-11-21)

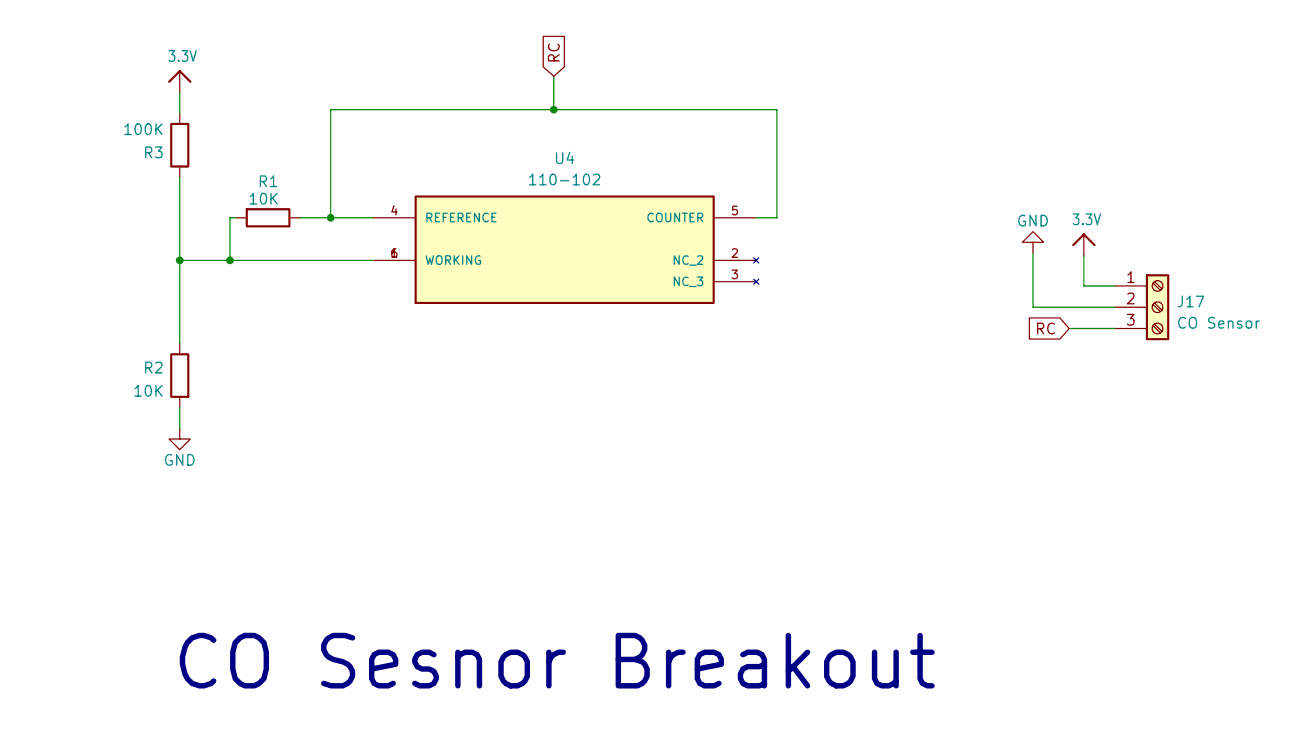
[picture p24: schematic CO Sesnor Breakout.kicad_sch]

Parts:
J17: CO Sensor; PinHeader_1x03_P2.54mm_Vertical
R1, R2: 10K; R_0805_2012Metric
R3: 100K; R_0805_2012Metric
U4: 110-102; CO Sensor; PARTREV April 2017

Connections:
3.3V: J17.1, R3.2
GND: J17.2, R2.2
unnamed: R1.2, R2.1, R3.1, U4.1 (WORKING), U4.6 (WORKING)
RC: J17.3, R1.1, U4.4 (REFERENCE), U4.5 (COUNTER)

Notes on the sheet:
CO Sesnor Breakout

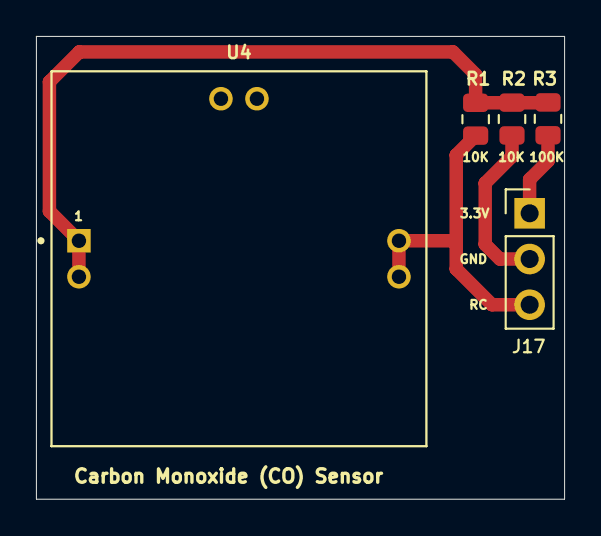
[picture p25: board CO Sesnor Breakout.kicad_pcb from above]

Board: 2 copper layers, 29.3 x 25.7 mm, 5 parts (0 on the bottom side), 4 nets.

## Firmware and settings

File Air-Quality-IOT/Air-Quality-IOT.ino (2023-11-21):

#include <BLEDevice.h>
#include <BLEServer.h>
#include <BLEUtils.h>
#include <BLE2902.h>
#include <Wire.h>
#include <Adafruit_Sensor.h>
#include <Adafruit_BME680.h>
#include <Adafruit_NeoPixel.h>
#include "COSensor.h"

// Pin Definitions
#define I2C_SDA 5
#define I2C_SCL 6
#define LED_PIN 20
#define BUZZER_PIN 1
#define BATTERY_PIN 4

// BME680 and CO Sensor Instances
Adafruit_BME680 bme;
COSensor coSensor(3, 2.125, 10.0, 0.10786);

// NeoPixel Setup
Adafruit_NeoPixel pixels(1, LED_PIN, NEO_GRB + NEO_KHZ800);

// BLE Variables
BLEServer* pServer = nullptr;
BLECharacteristic *pCombinedCharacteristic, *pLedCharacteristic, *pBuzzerCharacteristic, *pBatteryCharacteristic, *pCOCharacteristic;

// UUIDs
const char* SERVICE_UUID = "19b10000-e8f2-537e-4f6c-d104768a1214";
const char* COMBINED_CHARACTERISTIC_UUID = "19b10005-e8f2-537e-4f6c-d104768a1214"; // New UUID for combined data
const char* LED_CHARACTERISTIC_UUID = "19b10002-e8f2-537e-4f6c-d104768a1214";
const char* BUZZER_CHARACTERISTIC_UUID = "19b10003-e8f2-537e-4f6c-d104768a1214";
const char* BATTERY_CHARACTERISTIC_UUID = "19b10004-e8f2-537e-4f6c-d104768a1214";
const char* CO_CHARACTERISTIC_UUID = "6e400002-b5a3-f393-e0a9-e50e24dcca9e";

// Forward Declarations
void setupBLE();
void setupBME680();
void updateSensorData();
void updateBatteryLevel();
void updateCOData();

class MyServerCallbacks : public BLEServerCallbacks {
public:
    MyServerCallbacks(Adafruit_NeoPixel& pixels) : pixels(pixels) {}

    void onConnect(BLEServer* pServer) override {
        updateLedColor(0, 255, 0); // Green when connected
        triggerBuzzer();
    }

    void onDisconnect(BLEServer* pServer) override {
        updateLedColor(0, 0, 255); // Blue when disconnected
    }

private:
    Adafruit_NeoPixel& pixels;

    void updateLedColor(uint8_t red, uint8_t green, uint8_t blue) {
        pixels.setPixelColor(0, pixels.Color(red, green, blue));
        pixels.show();
    }

    void triggerBuzzer() {
        digitalWrite(BUZZER_PIN, HIGH);
        delay(500);
        digitalWrite(BUZZER_PIN, LOW);
    }
};

void setup() {
    Serial.begin(115200);
    pixels.begin();
    pinMode(BUZZER_PIN, OUTPUT);
    pinMode(BATTERY_PIN, INPUT);

    setupBME680();
    setupBLE();

    pixels.setPixelColor(0, pixels.Color(0, 0, 255)); // Blue when powered on
    pixels.show();
}

void loop() {
    if (pServer->getConnectedCount() > 0) {
        updateSensorData();
        updateBatteryLevel();
        updateCOData();

    }
}

void setupBLE() {
    BLEDevice::init("ESP32");
    pServer = BLEDevice::createServer();
    pServer->setCallbacks(new MyServerCallbacks(pixels));

    BLEService *pService = pServer->createService(SERVICE_UUID);

    // BME680 Characteristic
    pCombinedCharacteristic = pService->createCharacteristic(
                      COMBINED_CHARACTERISTIC_UUID,
                      BLECharacteristic::PROPERTY_READ   |
                      BLECharacteristic::PROPERTY_NOTIFY
                    );
    pCombinedCharacteristic->addDescriptor(new BLE2902());

    // LED Characteristic
    pLedCharacteristic = pService->createCharacteristic(
                      LED_CHARACTERISTIC_UUID,
                      BLECharacteristic::PROPERTY_WRITE
                    );
    pLedCharacteristic->addDescriptor(new BLE2902());

    // Buzzer Characteristic
    pBuzzerCharacteristic = pService->createCharacteristic(
                      BUZZER_CHARACTERISTIC_UUID,
                      BLECharacteristic::PROPERTY_WRITE
                   );
    pBuzzerCharacteristic->addDescriptor(new BLE2902());

    // Battery Characteristic
    pBatteryCharacteristic = pService->createCharacteristic(
                     BATTERY_CHARACTERISTIC_UUID,
                     BLECharacteristic::PROPERTY_READ |
                     BLECharacteristic::PROPERTY_NOTIFY
                    );
    pBatteryCharacteristic->addDescriptor(new BLE2902());

    // CO Characteristic
    pCOCharacteristic = pService->createCharacteristic(
                    CO_CHARACTERISTIC_UUID,
                     BLECharacteristic::PROPERTY_READ |
                     BLECharacteristic::PROPERTY_NOTIFY
                    );
    pCOCharacteristic->addDescriptor(new BLE2902());

    pService->start();

    BLEAdvertising *pAdvertising = BLEDevice::getAdvertising();
    pAdvertising->addServiceUUID(SERVICE_UUID);
    pAdvertising->setScanResponse(false);
    pAdvertising->setMinPreferred(0x0);
    BLEDevice::startAdvertising();
    Serial.println("Waiting for a client connection to notify...");
}

void setupBME680() {
    Wire.begin(I2C_SDA, I2C_SCL, 100000);
    if (!bme.begin(0x76, &Wire)) {
        Serial.println("Could not find a valid BME680 sensor, check wiring!");
        while (1);
    }
    bme.setTemperatureOversampling(BME680_OS_8X);
}

void updateSensorData() {
    if (!bme.performReading()) {
        Serial.println("Failed to perform reading :(");
        return;
    }

    // Send temperature and VOC as a combined string, separated by a comma
    String combinedData = String(bme.temperature) + "," + String(bme.gas_resistance);
    pCombinedCharacteristic->setValue(combinedData.c_str());
    pCombinedCharacteristic->notify();
    Serial.println("Combined data notified: " + combinedData);
    delay(1000);
}

void updateCOData() {
    // Send CO level as a raw value
    float concentration = coSensor.readConcentration();
    pCOCharacteristic->setValue(String(concentration).c_str());
    pCOCharacteristic->notify();
    Serial.print("CO Concentration: ");
    Serial.print(concentration);
    Serial.println(" ppm");
    delay(5000);
}

void updateBatteryLevel() {
    uint32_t Vbatt = analogRead(BATTERY_PIN);
    float Vbattf = 2 * Vbatt / 4095.0 * 3.3; // Calculate battery voltage
    if (Vbattf < 3.0) {
        pixels.setPixelColor(0, pixels.Color(255, 0, 0)); // Red when battery is low
        pixels.show();
        delay(1000);
        pixels.setPixelColor(0, pixels.Color(0, 0, 0)); // Turn off LED
        pixels.show();
        delay(1000);
    }
    pBatteryCharacteristic->setValue(String(Vbattf).c_str());
    pBatteryCharacteristic->notify();
    Serial.print("Battery Voltage: ");
    Serial.println(Vbattf, 3);
}

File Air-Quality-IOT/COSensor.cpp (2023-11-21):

// COSensor.cpp
#include "COSensor.h"
#include <Arduino.h>

COSensor::COSensor(int pin, float sensitivity, float loadResistor, float cOff)
    : _sensorPin(pin), _sensitivity(sensitivity), _loadResistor(loadResistor), _cOff(cOff) {
    _voltageRef = 1.2; // Default reference voltage
    _adcResolution = 4095; // Default ADC resolution
}

void COSensor::begin() {
    analogReadResolution(12); // Set ADC resolution to 12 bits
}

float COSensor::readConcentration() {
    int sensorValue = analogRead(_sensorPin);
    float sensorVoltage = (sensorValue / (float)_adcResolution) * _voltageRef;
    sensorVoltage -= _cOff;
    return (sensorVoltage / (_sensitivity / 1000.0)) / _loadResistor;
}

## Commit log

2023-11-21 Update index.html
    updated to include all BME680 sensor inputs and allows a buzzer to be controlled
2023-11-21 Update index.html
    added buzzer and battery percentage
2023-11-21 Update index.html
    LED fixes
2023-11-21 filter devices
